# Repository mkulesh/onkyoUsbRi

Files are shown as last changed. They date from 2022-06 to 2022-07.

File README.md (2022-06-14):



# Onkyo Remote Control Interface: USB-Ri adapter based on STM32F303

Onkyo HiFi devices (players, amplifiers, receives) usually have so called RI port on the back panel.  It is a 3.5mm mono jack that can be used to connect other Onkyo elements. For example if we connect an Onkyo amplifier with an IR remote, the amplifier IR remote can control both the amplifier and the player thanks to the Remote Interactive port. In fact we can daisy chain several Onkyo elements (Tape player, DVD player, etc.) and control all the elements with a single remote.

The problem is that modern Onkyo players and receivers do not more support older devices like tape-decks or MD-players. The hardware still exist but such a support is removed from actual firmware. 

However, we can control older Onkyo devices from a PC using small USB-Ri adapter and appropriate software. This project contains PCB layout and firmware for such an adapter.

The  adapter is based on  STM32F303 MCU. USB interface is implemented using FT321XS IC. The device is powered from USB and contains a 3.5mm mono jack used to attach it to an Onkyo device.

## PCB

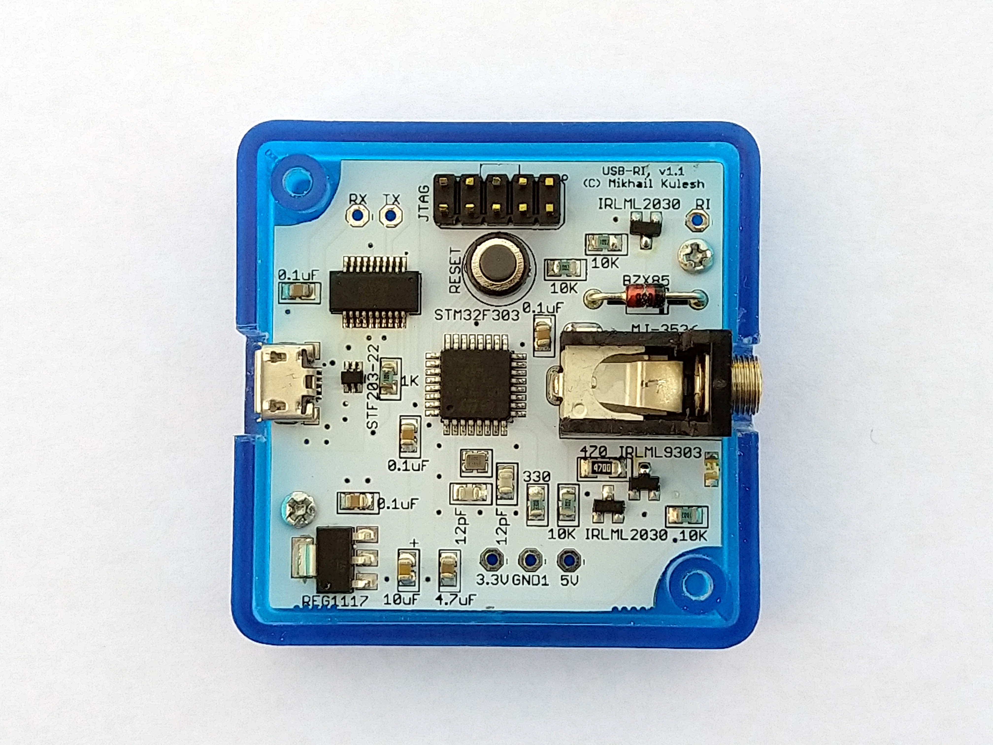
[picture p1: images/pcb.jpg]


## Adapter

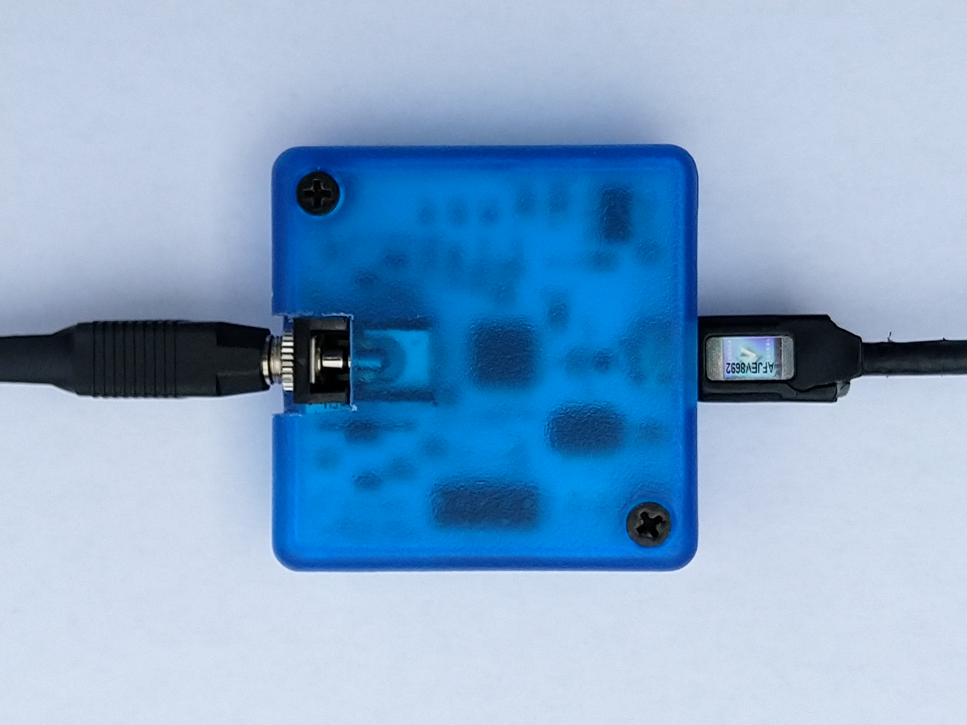
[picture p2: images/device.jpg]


## Schematic

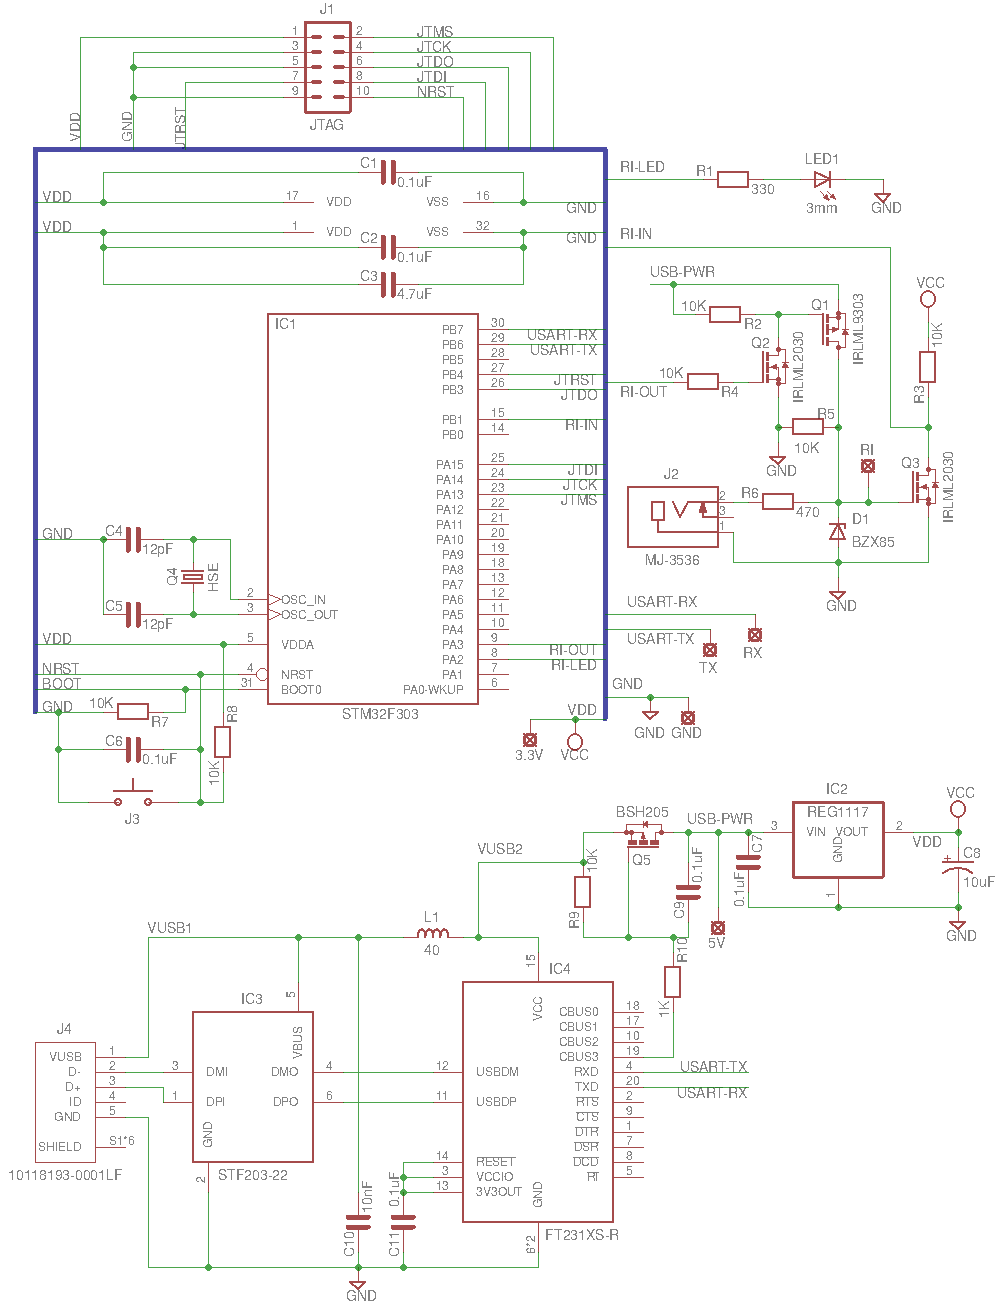
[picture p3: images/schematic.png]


## Desktop App

In order to control Onkyo via this adapter, [Enhanced Music Controller](https://github.com/mkulesh/onpc) shall be used:

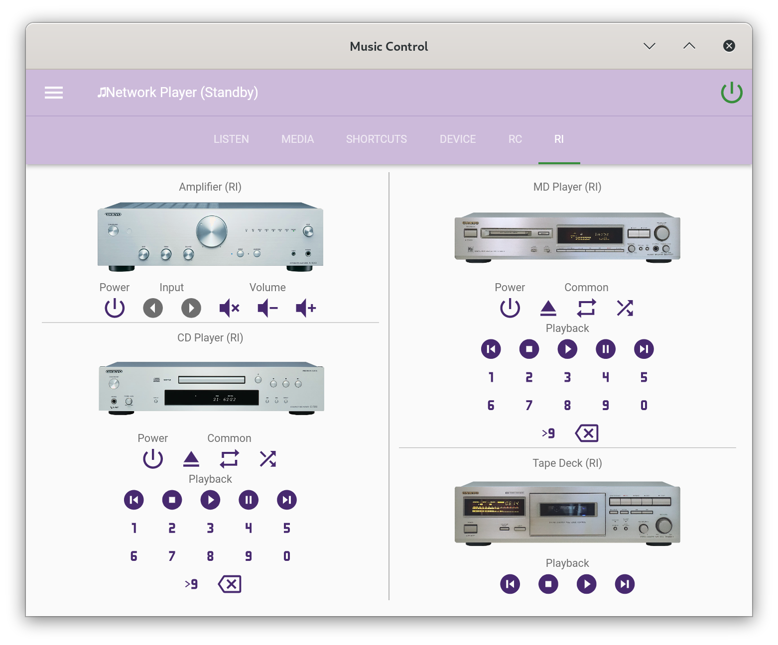
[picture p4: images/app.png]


## Resources
- https://github.com/docbender/Onkyo-RI
- https://github.com/intelfx/onkyo-ri
- http://fredboboss.free.fr/articles/onkyo_ri.php

## License

This software is published under the *GNU General Public License, Version 3*

Copyright © 2022 by Mikhail Kulesh

This program is free software: you can redistribute it and/or modify it under the terms of the GNU General Public License as
published by the Free Software Foundation, either version 3 of the License, or (at your option) any later version.

This program is distributed in the hope that it will be useful, but WITHOUT ANY WARRANTY; without even the implied warranty
of MERCHANTABILITY or FITNESS FOR A PARTICULAR PURPOSE.  See the GNU General Public License for more details. You should have
received a copy of the GNU General Public License along with this program.

If not, see [www.gnu.org/licenses](https://www.gnu.org/licenses).

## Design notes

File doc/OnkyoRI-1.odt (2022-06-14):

## Onkyo RI Protocol (http://fredboboss.free.fr/articles/onkyo_ri.php)

- Published on 11 June 2011
- by Fred (http://fredboboss.free.fr/pages/about.php).

## Onkyo DX-701 CD Player

I own that 20 years old CD Player, it still sounds very good :

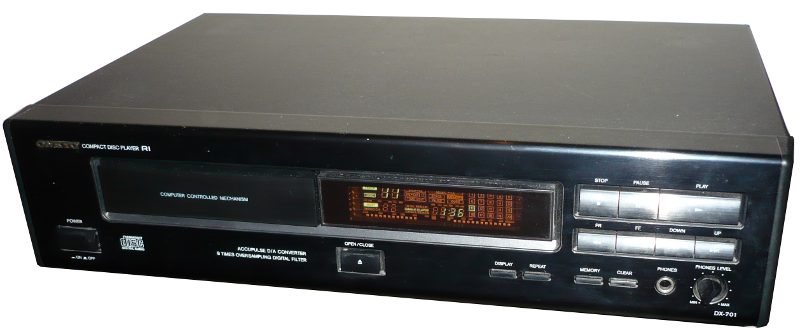
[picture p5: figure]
DX-701

At the back of the player you find the RI port (Remote Interactive). It is a 3.5mm mono jack that can be used to connect other Onkyo elements :

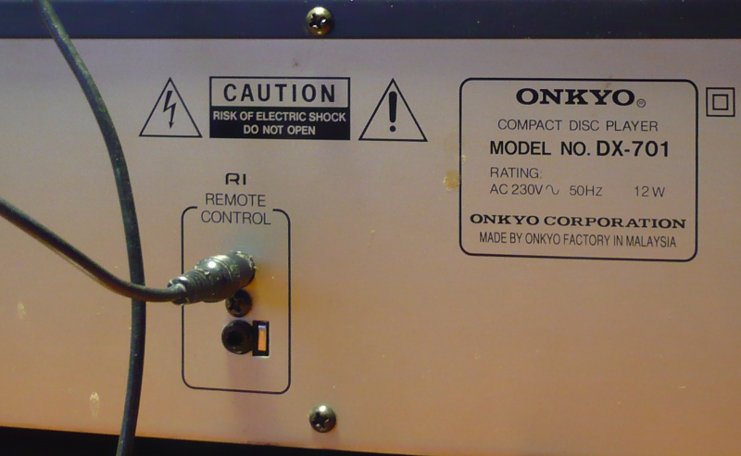
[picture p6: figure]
RI

For example if you connect an Onkyo amplifier with an IR remote, the amplifier IR remote can control both the amplifier and the player thanks to the Remote Interactive port. In fact you can daisy chain several onkyo elements (Tape player, DVD player, etc.) and control all the elements with a single remote.

This is a very clever idea and today all Onkyo HIFI elements still sport a Remote Interactive port.

## Onkyo RI protocol

The LIRC project (http://www.lirc.org/) provides information about the RI protocol :

- http://lirc.sourceforge.net/remotes/onkyo/Remote_Interactive
- http://lirc.sourceforge.net/remotes/onkyo/Remote_Interactive_TX-SR505SE

The files give the pulses encoding under LIRC format is as follows (durations are in µseconds) :

bits 12

flags SPACE_ENC|CONST_LENGTH

eps 30

aeps 100

header 3000 1000

one 1000 2000

zero 1000 1000

ptrail 1000

gap 67000

toggle_bit 0

From there it is very easy to draw the form of the signal. It is space encoded, with a header and a trailer and the message is composed of 12 bits :

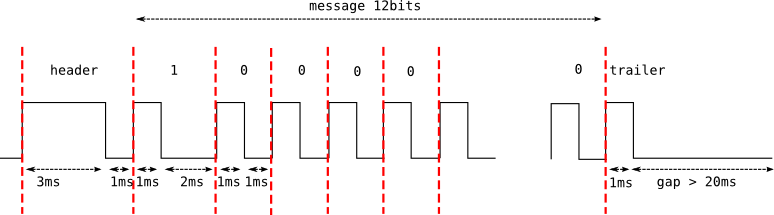
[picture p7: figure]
pulses

Now we know the waveform and the encoding of the Remote Interactive signal, what about the signal level ?

Given the age of the CD Player (and of the RI protocol) the signal is TTL, that is :

- 0 (low) is 0 Volt
- 1 (high) is 5 Volts

For more details about TTL you may refer to Wikipedia (https://en.wikipedia.org/wiki/Transistor–transistor_logic#Interfacing_considerations)

## RI Codes for DX-701

The codes for my DX-701 CD Player cover all the functionalities that are accessible on the device facade :

# RI codes for DX-701 CD Player

# RI codes for DX-701 CD Player

CD_Forward 0x0F00

CD_Rewind 0x0F01

CD_Repeat 0x0F06

CD_Clear 0x0F08

CD_Memory 0x0F09

CD_Display 0x0F0A

CD_Eject 0x0F0B

CD_8 0x0F0C

CD_9 0x0F0D

CD_0 0x0F0E

CD_Digits 0x0F0F

CD_1 0x0F10

CD_2 0x0F11

CD_3 0x0F12

CD_4 0x0F13

CD_5 0x0F18

CD_6 0x0F19

CD_7 0x0F1A

CD_Play 0x0F1B

CD_Stop 0x0F1C

CD_Next 0x0F1D

CD_Prev 0x0F1E

CD_Pause 0x0F1F

CD_Random 0x0F46

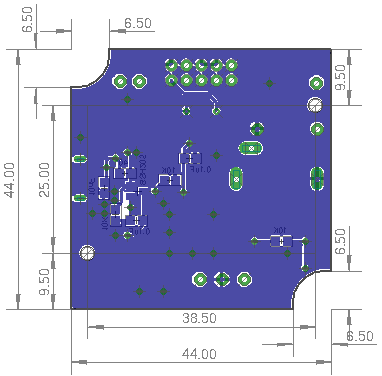
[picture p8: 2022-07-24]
images/pcb-bottom.png

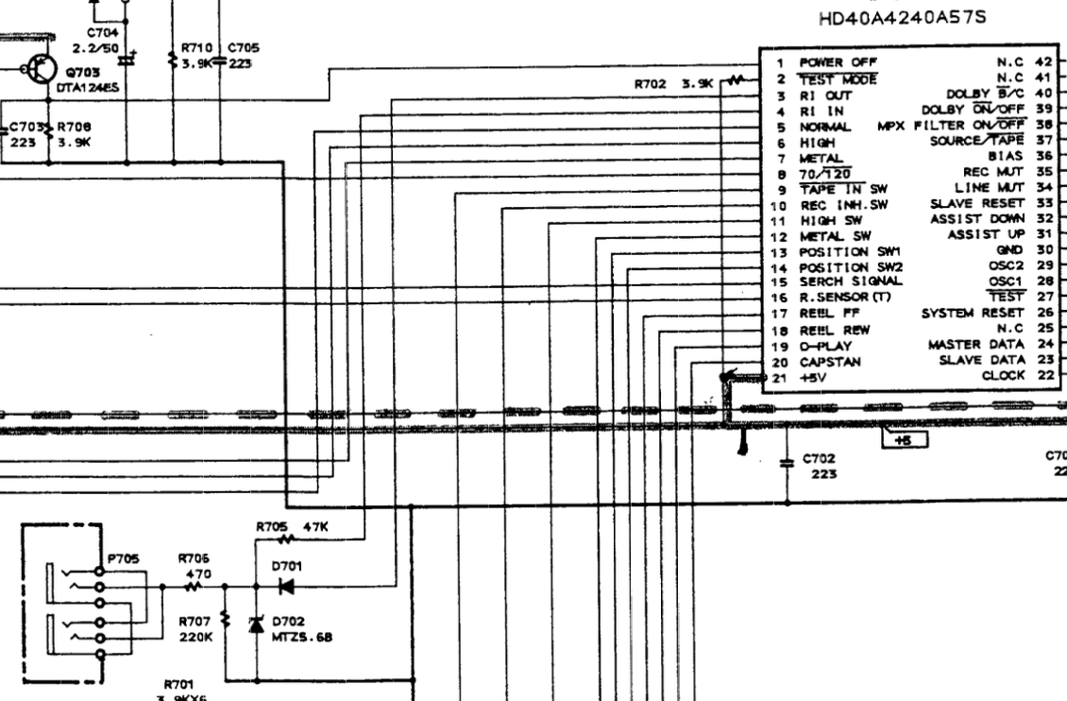
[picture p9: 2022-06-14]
doc/ri_ta_6510.png

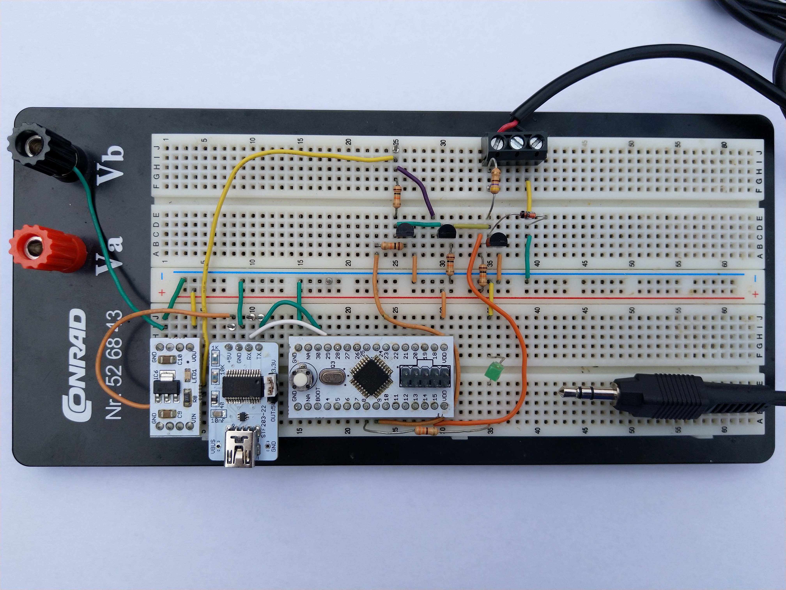
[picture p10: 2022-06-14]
images/prototype.jpg

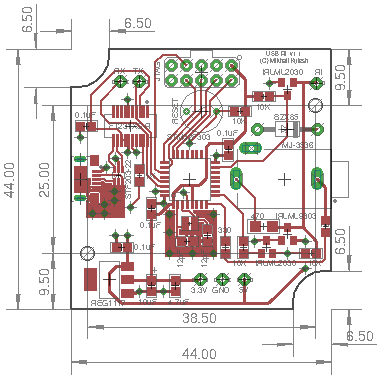
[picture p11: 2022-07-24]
images/pcb-top.png

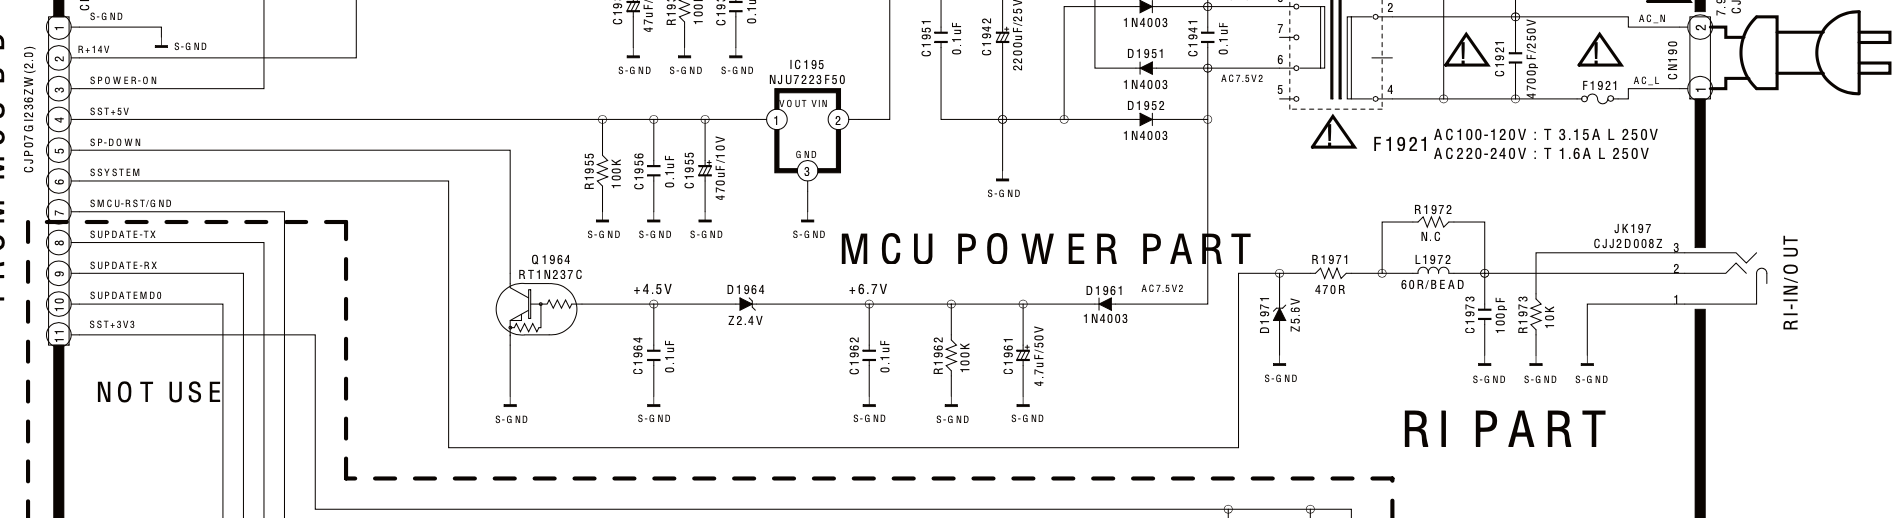
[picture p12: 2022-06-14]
doc/ri_a_9010_1.png

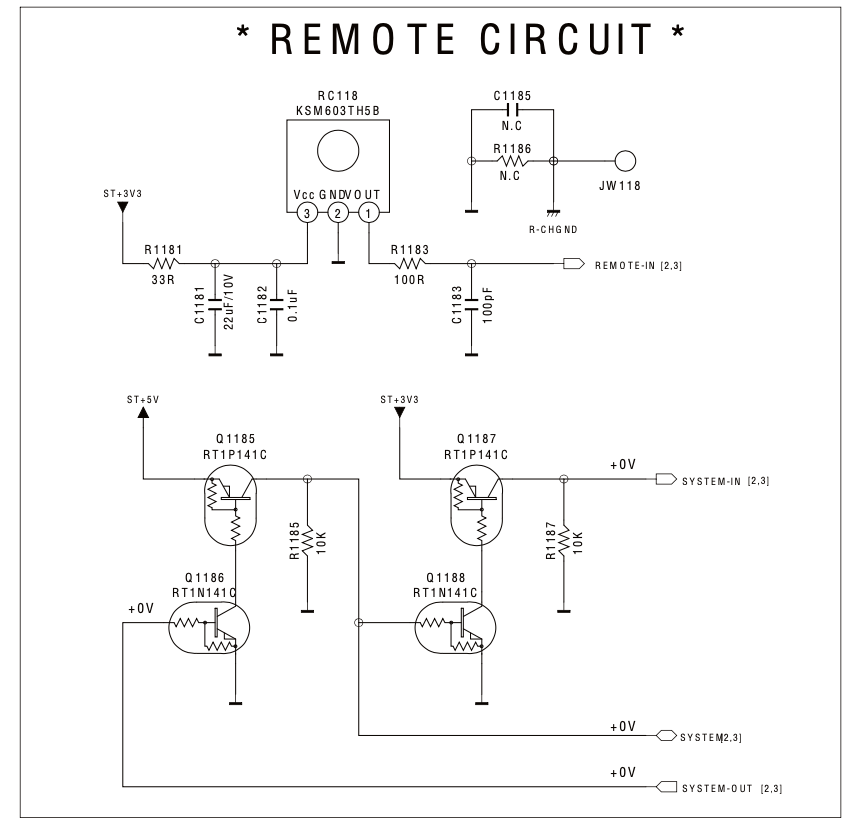
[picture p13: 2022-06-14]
doc/ri_a_9010_2.png

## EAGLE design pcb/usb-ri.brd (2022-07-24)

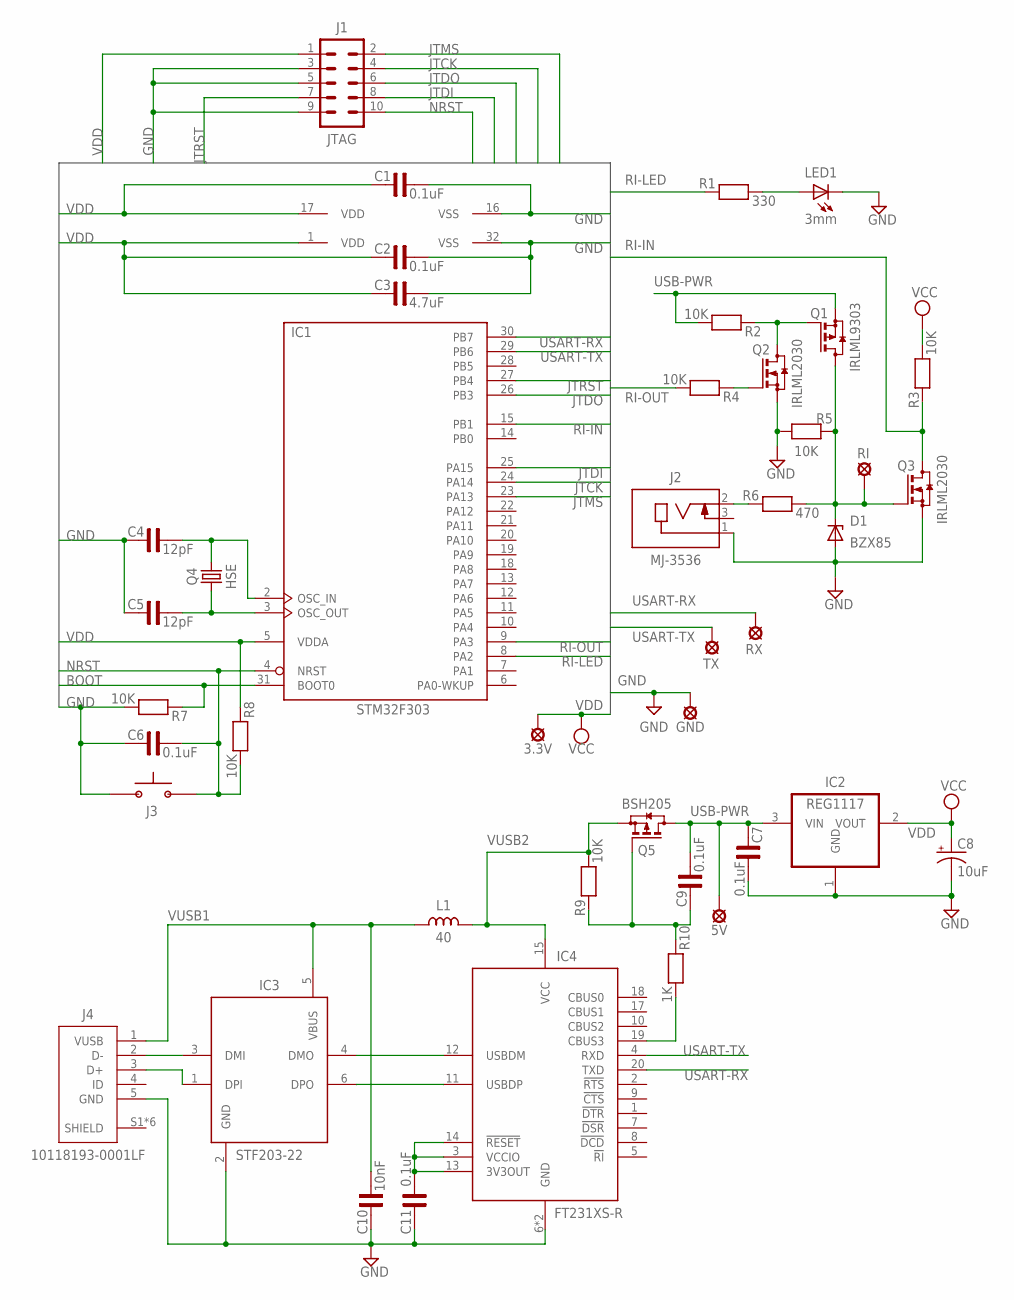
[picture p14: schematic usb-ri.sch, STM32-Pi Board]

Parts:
3.3V, 5V: LSP10
C1, C2, C6, C7, C9, C11: 0.1uF; C0805
C3: 4.7uF; C0805
C4, C5: 12pF; C0805
C8: 10uF; CPOL0805
C10: 10nF; C0805
D1: BZX85; DO41Z10
GND: LSP10
IC1: STM32F303; LQFP32
IC2: REG1117; SOT223
IC3: STF203-22; SC70-6
IC4: FT231XS-R; SOP63P599X175-20N
J1: JTAG; MA05-2
J2: MJ-3536; AUDIO-MJ-3536
J3: RESET; BUTTON-FSM14JRT
J4: 10118193-0001LF; MICRO-USB-10118193-0001LF
L1: 40; L0805
LED1: 3mm; CHIP-LED0805
Q1: IRLML9303; SOT23
Q2, Q3: IRLML2030; SOT23
Q4: HSE; Q-FA-128
Q5: BSH205; SOT23
R1: 330; R0805
R2, R3, R4, R5, R7, R8, R9: 10K; R0805
R6: 470; R1206
R10: 1K; R0805
RI: LSP10
RX: LSP10
TX: LSP10

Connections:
BOOT: IC1.31 (BOOT0), R7.1
D+: IC3.1 (DPI), J4.3 (D+)
D-: IC3.3 (DMI), J4.2 (D-)
GND: C1.2, C2.2, C3.2, C4.1, C5.1, C6.1, C7.2, C8.2- (-), C10.1, C11.1, D1.A, GND.MP, IC1.16 (VSS), IC1.32 (VSS), IC2.1 (GND), IC3.2 (GND), IC4.6 (GND), IC4.16 (GND), J1.3, J1.5, J1.9, J2.1, J3.P$1 (1), J4.5 (GND), LED1.C, Q2.2 (S), Q3.2 (S), R5.2, R7.2
JTCK: IC1.24 (PA14), J1.4
JTDI: IC1.25 (PA15), J1.8
JTDO: IC1.26 (PB3), J1.6
JTMS: IC1.23 (PA13), J1.2
JTRST: IC1.27 (PB4), J1.7
unnamed: Q1.1 (G), Q2.3 (D), R2.1
unnamed: J2.2, R6.1
unnamed: IC3.4 (DMO), IC4.12 (USBDM)
unnamed: C5.2, IC1.3 (OSC_OUT), Q4.1
unnamed: IC3.6 (DPO), IC4.11 (USBDP)
unnamed: LED1.A, R1.2
unnamed: C11.2, IC4.3 (VCCIO), IC4.13 (3V3OUT), IC4.14 (!RESET)
unnamed: Q2.1 (G), R4.1
unnamed: C9.1, Q5.1 (G), R9.1, R10.1
unnamed: IC4.19 (CBUS3), R10.2
unnamed: D1.C, Q1.3 (D), Q3.1 (G), R5.1, R6.2, RI.MP
unnamed: C4.2, IC1.2 (OSC_IN), Q4.3 (2)
NRST: C6.2, IC1.4 (NRST), J1.10, J3.P$2 (2), R8.2
RI-IN: IC1.15 (PB1), Q3.3 (D), R3.1
RI-LED: IC1.8 (PA2), R1.1
RI-OUT: IC1.9 (PA3), R4.2
USART-RX: IC1.30 (PB7), IC4.20 (TXD), RX.MP
USART-TX: IC1.29 (PB6), IC4.4 (RXD), TX.MP
USB-PWR: 5V.MP, C7.1, C9.2, IC2.3 (VIN), Q1.2 (S), Q5.3 (D), R2.2
VDD: 3.3V.MP, C1.1, C2.1, C3.1, C8.1+ (+), IC1.1 (VDD), IC1.5 (VDDA), IC1.17 (VDD), IC2.2 (VOUT), J1.1, R3.2, R8.1
VUSB1: C10.2, IC3.5 (VBUS), J4.1 (VUSB), L1.1
VUSB2: IC4.15 (VCC), L1.2, Q5.2 (S), R9.2

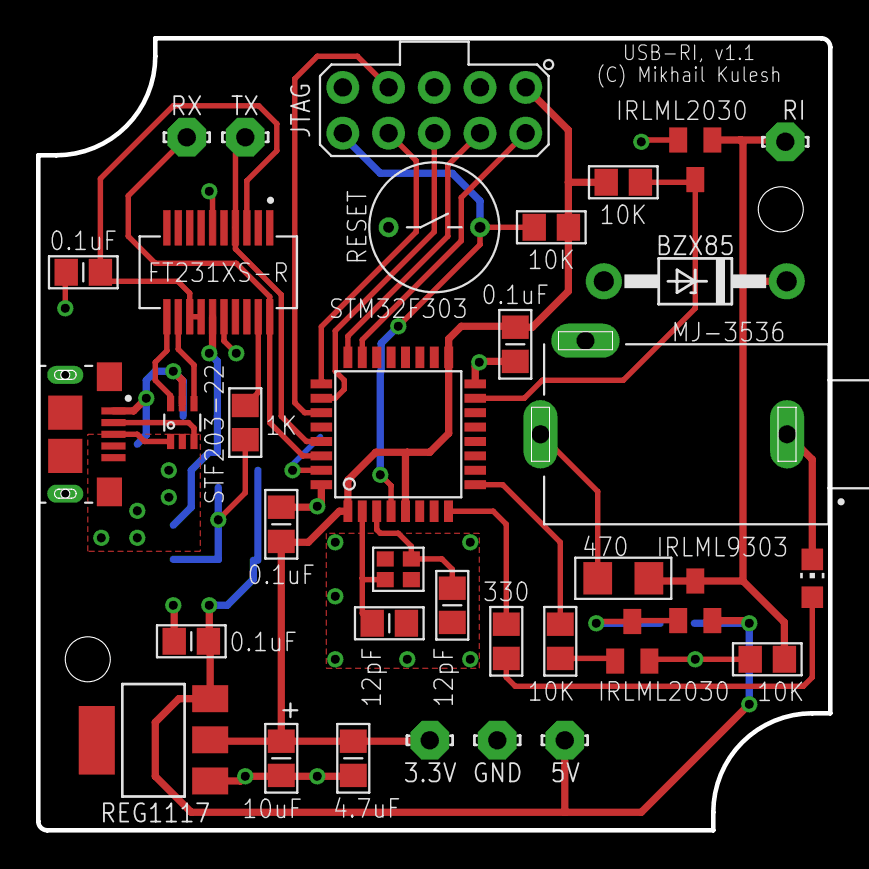
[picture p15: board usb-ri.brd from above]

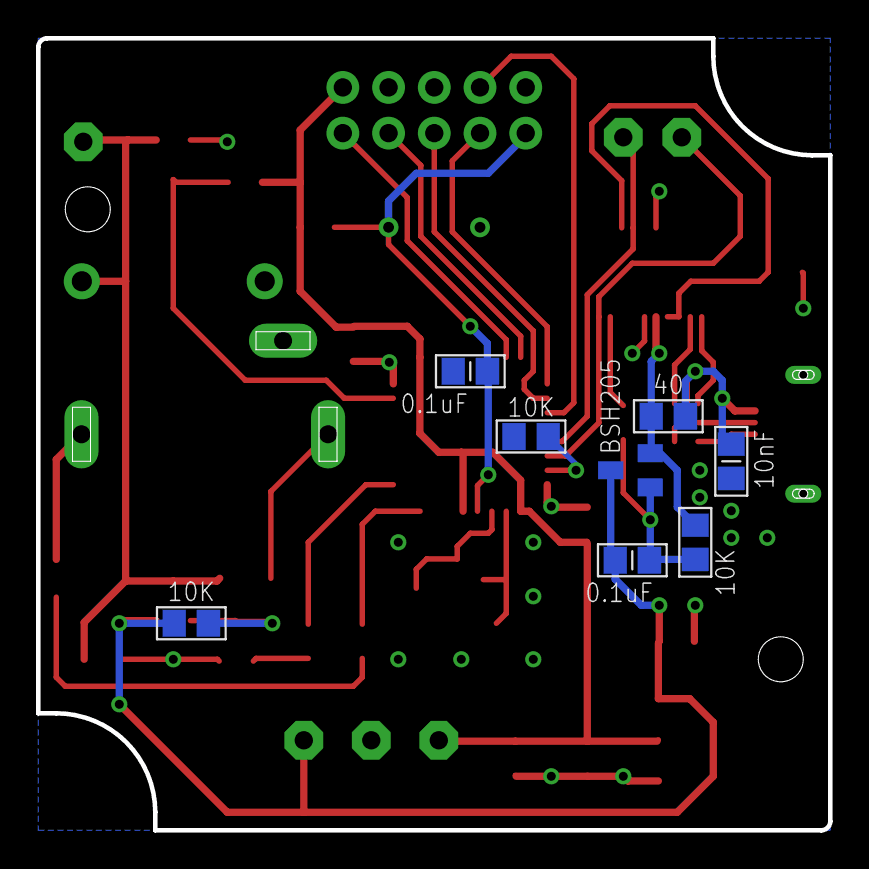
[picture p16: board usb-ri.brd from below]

Board: 2 copper layers, 44.0 x 44.0 mm, 43 parts (8 on the bottom side), 31 nets.

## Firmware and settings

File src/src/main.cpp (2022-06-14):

/*
 * onkyoUsbRi: Onkyo RI control
 * 
 * Copyright (C) 2021. Mikhail Kulesh
 *
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
 * This program is distributed in the hope that it will be useful, but WITHOUT ANY WARRANTY; without
 * even the implied warranty of MERCHANTABILITY or FITNESS FOR A PARTICULAR PURPOSE. See the
 * GNU General Public License for more details. You should have received a copy of the GNU General
 * Public License along with this program.
 */

#include "OnkyoRi.h"
#include "EventQueue.h"

using namespace StmPlusPlus;

#define USART_DEBUG_MODULE ""

class MyApplication
{
private:
    UsartLogger usart;
    IOPin riLed, mco;
    
    // RI input pin and interrupt
    static const uint16_t RI_INPUT_PIN = GPIO_PIN_1;    
    static const IRQn_Type RI_INPUT_IRQN = EXTI1_IRQn;
    IOPin riInput, riOutput;
    
    // RI command processing
    OnkyoRiInputProcessor inputProcessor;
    OnkyoRiOutputProcessor outputProcessor;

    // Event processing
    enum class Event
    {
        RI_CMD_LOW = 0,
        RI_CMD_HIGH = 1,
        RI_CMD_START = 2,
        USART_INPUT = 3
    };
    StmPlusPlus::EventQueue<Event, 100> eventQueue;

public:
    
    MyApplication () :
        usart(Usart::USART_1, IOPort::B, GPIO_PIN_6, GPIO_PIN_7, GPIO_SPEED_HIGH, 115200),
        riLed(IOPort::A, GPIO_PIN_2, GPIO_MODE_OUTPUT_PP),
        mco(IOPort::A, GPIO_PIN_8, GPIO_MODE_AF_PP),
        riInput(IOPort::B, RI_INPUT_PIN, GPIO_MODE_IT_RISING_FALLING),
        riOutput(IOPort::A, GPIO_PIN_3, GPIO_MODE_OUTPUT_PP, GPIO_NOPULL),
        inputProcessor(TimerBase::TIM_2),
        outputProcessor(riOutput, TimerBase::TIM_3)
    {
        mco.activateClockOutput(RCC_MCO1SOURCE_PLLCLK, RCC_MCODIV_2);
    }
    
    virtual ~MyApplication ()
    {
        // empty
    }
    
    void run ()
    {
        usart.initInstance();
       
        riLed.setHigh();
        USART_DEBUG("--------------------------------------------------------" << UsartLogger::ENDL);
        USART_DEBUG("MCU frequency: " << System::getMcuFreq() << UsartLogger::ENDL);
        riLed.setLow();
        
        // Activate interrupts for RI input
        HAL_NVIC_SetPriority(RI_INPUT_IRQN, 1, 0);
        HAL_NVIC_EnableIRQ(RI_INPUT_IRQN);

        // Activate interrupts for USART
        usart.startInterrupt(InterruptPriority(2, 0));
        usart.receiveIt(outputProcessor.usartBuffer, OnkyoRiOutputProcessor::USART_CMD_LENGHT);
        
        while (true)
        {
            if (!eventQueue.empty())
            {   
                Event event = eventQueue.get();
                switch(event)
                {
                case Event::RI_CMD_START:
                    USART_DEBUG("RI: ");
                    riLed.setHigh();
                    inputProcessor.processMsgStart();
                    break;
                case Event::RI_CMD_LOW:
                case Event::RI_CMD_HIGH:
                    USART_DEBUG("" << int(event))
                    if (inputProcessor.processMsgBit(event == Event::RI_CMD_LOW ? false : true))
                    {
                        USART_DEBUG(" = " << UsartLogger::HEX << inputProcessor.command 
                                    << UsartLogger::DEC << UsartLogger::ENDL);
                        riLed.setLow();
                    }
                    break;
                case Event::USART_INPUT:
                    if (outputProcessor.processUsartIrq())
                    {
                        riLed.setHigh();
                        USART_DEBUG(UsartLogger::ENDL 
                                    << "USART: " << UsartLogger::HEX << outputProcessor.command 
                                    << UsartLogger::DEC << UsartLogger::ENDL);
                        HAL_NVIC_DisableIRQ(RI_INPUT_IRQN);
                        outputProcessor.sendBlocking();
                        HAL_NVIC_EnableIRQ(RI_INPUT_IRQN);
                        riLed.setLow();
                        usart.receiveIt(outputProcessor.usartBuffer, OnkyoRiOutputProcessor::USART_CMD_LENGHT);
                    }
                    break;
                }
            }
            __NOP();
        }
    }
    
    void processRiInputIrq ()
    {
        if (__HAL_GPIO_EXTI_GET_FLAG(RI_INPUT_PIN))
        {
            int val = inputProcessor.processPinIrq(riInput.getBit());
            if (val >= 0)
            {
                eventQueue.put(Event(val));
            }
        }
        HAL_GPIO_EXTI_IRQHandler(RI_INPUT_PIN);
    }
    
    void processUsartIrq ()
    {
        usart.processInterrupt();
        eventQueue.put(Event::USART_INPUT);
    }
};

MyApplication * appPtr = NULL;

int main (void)
{
    // Note: check the Value of the External oscillator mounted in PCB
    // and set this value in the file stm32f3xx_hal_conf.h
    
    HAL_Init();
    
    IOPort defaultPortA(IOPort::PortName::A, GPIO_MODE_INPUT, GPIO_PULLDOWN, GPIO_SPEED_LOW);
    IOPort defaultPortB(IOPort::PortName::B, GPIO_MODE_INPUT, GPIO_PULLDOWN, GPIO_SPEED_LOW);
    IOPort defaultPortC(IOPort::PortName::C, GPIO_MODE_INPUT, GPIO_PULLDOWN, GPIO_SPEED_LOW);
    
    do
    {
        System::setClock(RCC_HSE_PREDIV_DIV2, RCC_PLL_MUL9, FLASH_LATENCY_2, System::RtcType::RTC_INT);
    }
    while (System::getMcuFreq() != 72000000L);
    
    MyApplication app;
    appPtr = &app;
    
    app.run();
}

extern "C" void SysTick_Handler (void)
{
    HAL_IncTick();
}

extern "C" void EXTI1_IRQHandler (void)
{
    appPtr->processRiInputIrq();
}

extern "C" void USART1_IRQHandler (void)
{
    appPtr->processUsartIrq();
}

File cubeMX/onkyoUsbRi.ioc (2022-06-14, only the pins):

Mcu.UserName=STM32F303K8Tx
PA13.Signal=SYS_JTMS-SWDIO
PA14.Signal=SYS_JTCK-SWCLK
PA15.Signal=SYS_JTDI
PA2.GPIO_Label=RI-LED
PA2.Signal=GPIO_Output
PA3.GPIO_Label=RI-OUT
PA3.Signal=GPIO_Output
PA8.Signal=RCC_MCO
PB1.GPIO_Label=RI-IN
PB1.Signal=GPXTI1
PB3.Signal=SYS_JTDO-TRACESWO
PB4.Signal=SYS_NJTRST
PB6.Signal=USART1_TX
PB7.Signal=USART1_RX

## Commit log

2022-06-14 Fixed PCB bug: connection of USB port
    [usb-ri.brd, usb-ri.sch]
2022-07-24 New PCB revision
    [onkyoUsbRi Run.cfg, usb-ri.brd]

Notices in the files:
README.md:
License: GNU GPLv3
